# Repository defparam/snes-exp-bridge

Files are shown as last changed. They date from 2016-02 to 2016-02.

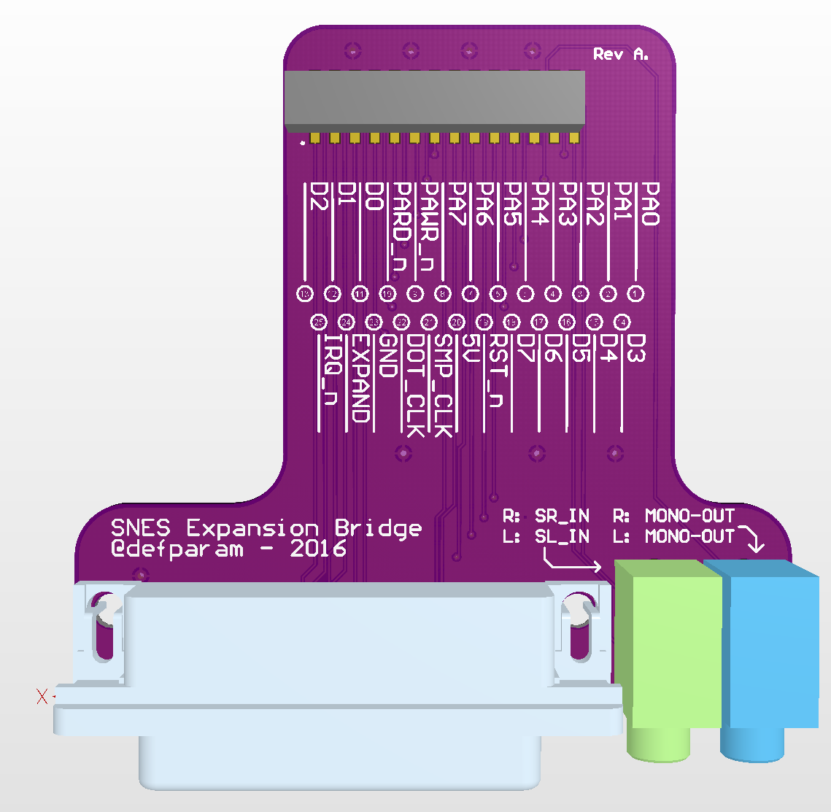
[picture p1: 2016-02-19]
photos/board1.png

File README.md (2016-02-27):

# snes-exp-bridge
This project is intended to create a bridge board interface to the SNES expansion port broken out to DB-25 and 3.5mm barrel audio. The expansion port requires a costly proprietary connector from SAMTEC (MEC2-30-01-L-DV). The idea is instead of creating projects which source this connector, all downstream projects can now instead mate with the DB-25 connector which is cheaper and easier for interfacing. There are no active electrical components for this board. This repo contains altium design files of the schematic/layout, photos and pdf docs.

Enjoy!
Evan

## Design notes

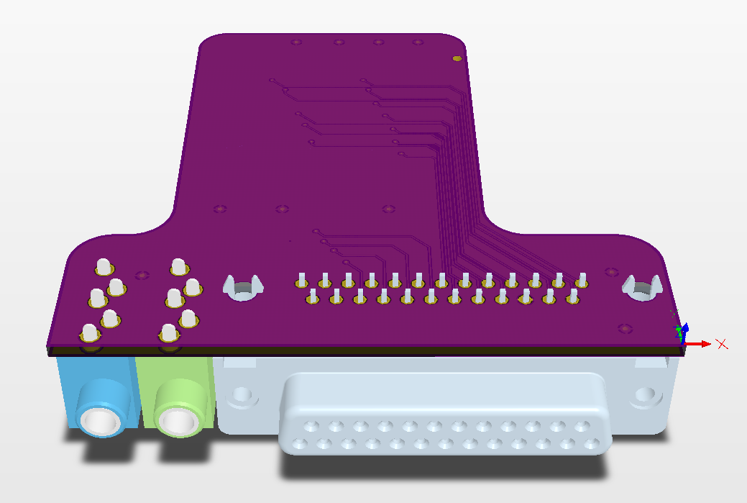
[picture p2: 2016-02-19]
photos/board3.png

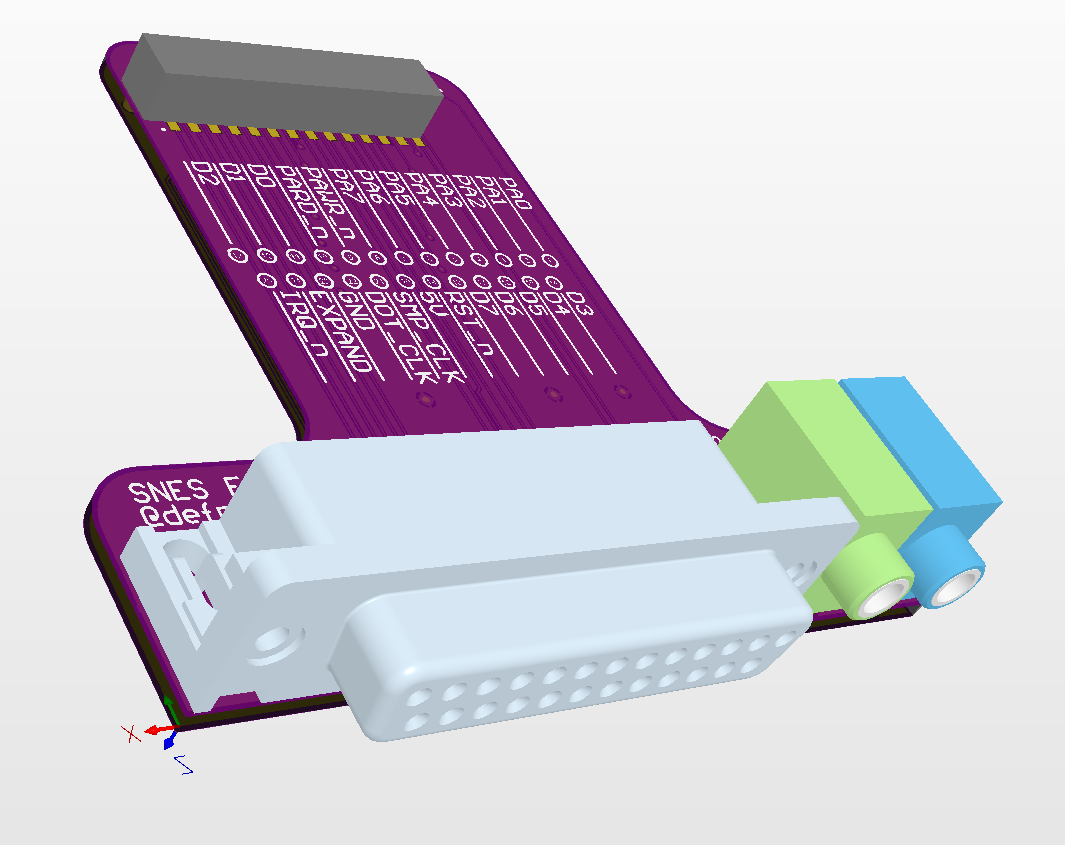
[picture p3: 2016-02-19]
photos/board2.png

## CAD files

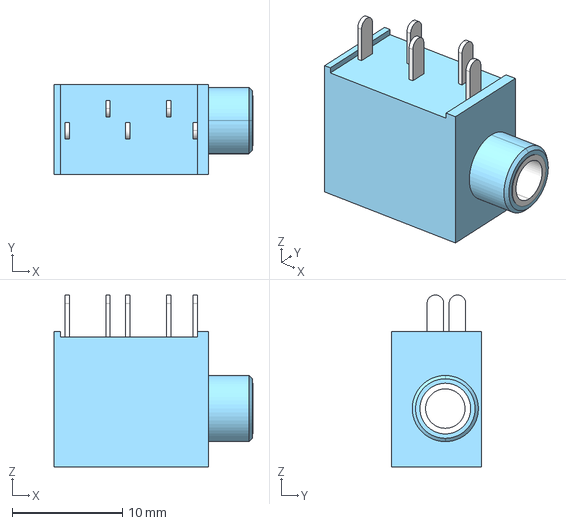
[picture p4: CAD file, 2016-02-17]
altium/step/SJ1-3535NG-BE.stp
18.1 x 8.20 x 15.6 mm

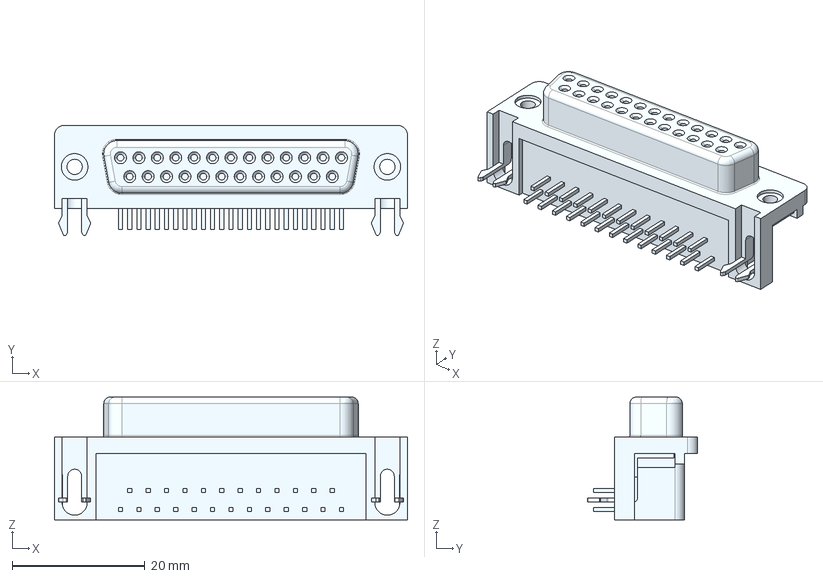
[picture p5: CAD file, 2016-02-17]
altium/step/TE_conn_DB_25.stp
53.1 x 16.6 x 18.5 mm

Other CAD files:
altium/step/SJ1-3535NG-GR.stp

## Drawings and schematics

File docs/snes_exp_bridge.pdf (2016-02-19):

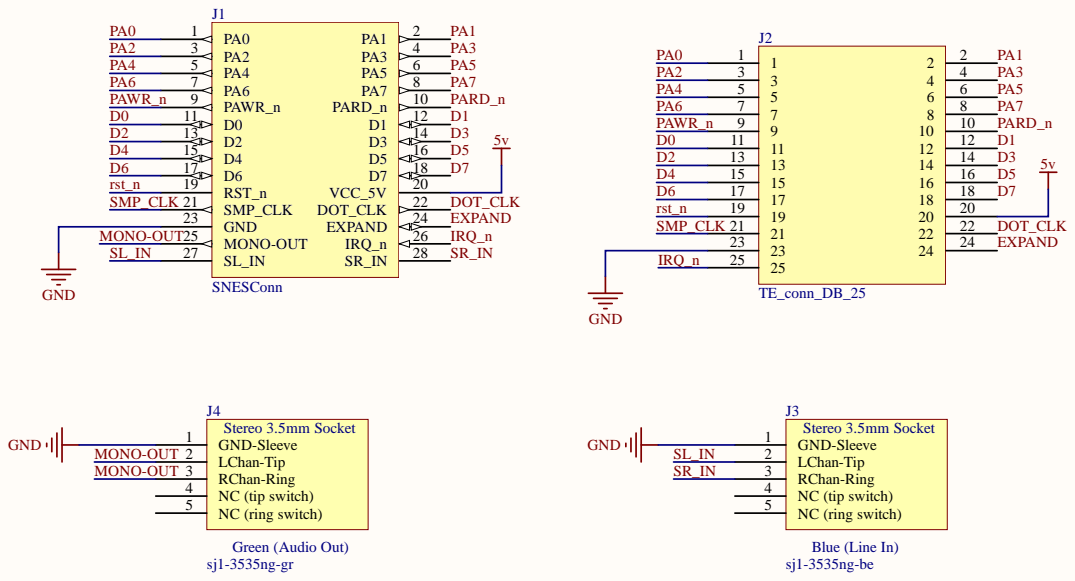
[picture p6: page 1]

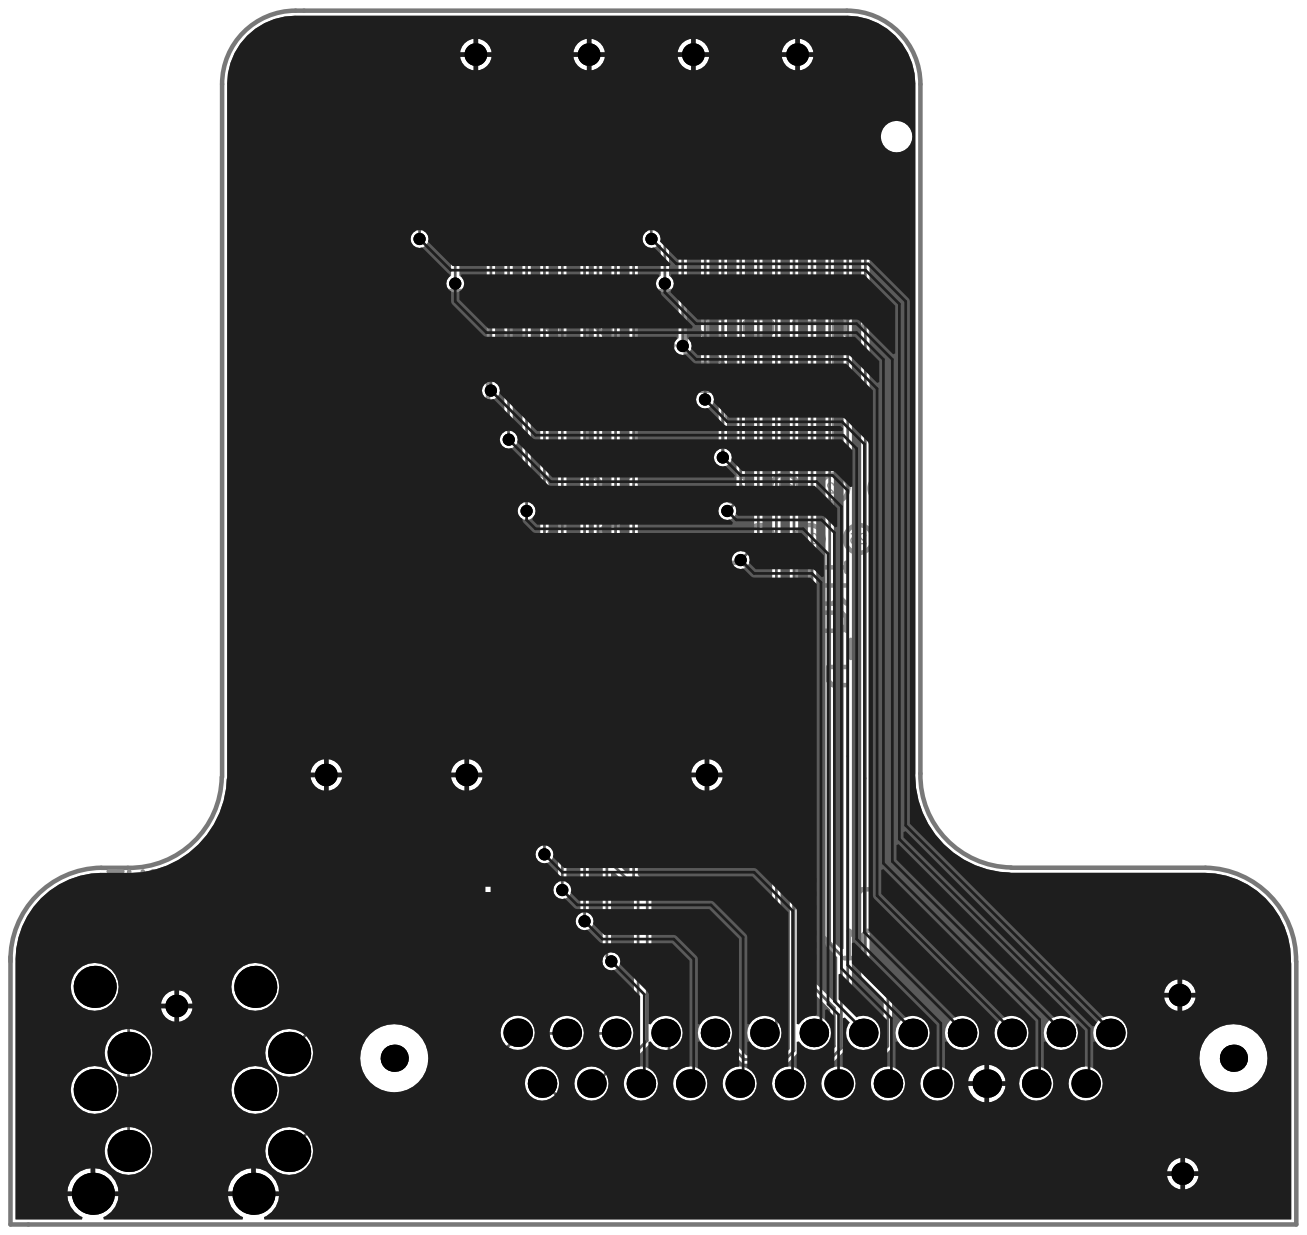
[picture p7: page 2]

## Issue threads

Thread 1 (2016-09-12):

BOM

qwertymodo, 2016-09-12:
Can you post the part numbers for the connectors used?  I know there's basically just 2 parts, so a full BOM is probably overkill, but mostly I'm trying to figure out what audio jack you're using.  The DB-25 connector is probably pretty standard, but audio barrel jacks come in all kinds of shapes, sizes, and footprints.

defparam, 2016-09-12:
For EXP BOARD notable parts (digikey links):

TE Connectivity 1734350-1 - https://www.digikey.com/product-detail/en/te-connectivity-amp-connectors/1734350-1/A35111-ND/1279824
CUI Inc. SJ1-3535NG-GR - https://www.digikey.com/product-detail/en/cui-inc/SJ1-3535NG-GR/CP1-3535NG-GR-ND/2295993
CUI Inc. SJ1-3535NG-BE - https://www.digikey.com/product-detail/en/cui-inc/SJ1-3535NG-BE/CP1-3535NG-BE-ND/2295992

For 21FX Rev C notable parts (digikey links):

3M 8432-11B1-RK-TP - https://www.digikey.com/product-detail/en/3m/8432-11B1-RK-TP/3M3211B1-ND/1026472
Microchip SST39SF010A-70-4C-NHE - https://www.digikey.com/product-detail/en/microchip-technology/SST39SF010A-70-4C-NHE/SST39SF010A-70-4C-NHE-ND/2297825
Norcomp Inc. 182-025-113R531 - https://www.digikey.com/product-detail/en/norcomp-inc/182-025-113R531/182-25ME-ND/858361

The holes I used for the audio connectors are not slotted (because OSHPark doesn't do plated slots). So Those holes are really large however it still works for those parts. If you aren't using audio you can safely omit the audio connectors as they are fairly expensive. Since you are looking at 21FX I also put some parts I used above. FYI you need an external programmer to program byuu's IPLROM onto the microchip EEPROM. Lastly for the 21FX you need the adafruit FTDI board (yeahhh, 21FX needs a tech refresh, it was intended originally to not have USB).

qwertymodo, 2016-09-12:
Perfect, thanks.

defparam, 2016-09-12:
21FX (couple more parts I missed):

CTS CB3-3I-40M0000 - https://www.digikey.com/product-detail/en/cts-frequency-controls/CB3-3I-40M0000/CTX314CT-ND/663676
Altera EPM7064STC44-10N - https://www.digikey.com/product-detail/en/altera/EPM7064STC44-10N/544-2020-ND/1084671
Adafruit 232H breakout - https://www.adafruit.com/products/2264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

Closed 2016-09-12.

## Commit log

2016-02-14 Adding EXP-Bridge project to GitHub
    [snes_exp_bridge.PcbDoc, snes_exp_bridge.PrjPcb, snes_exp_bridge.SchDoc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]
2016-02-17 Adding step files
    [SJ1-3535NG-BE.stp, SJ1-3535NG-GR.stp, TE_conn_DB_25.stp]
2016-02-17 REV A Final
    [snes_exp_bridge.PcbDoc, snes_exp_bridge.PrjPcb, snes_exp_bridge.SchDoc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]
2016-02-19 Updating final design files, modified license, added PDF schematic and photos.
    [snes_exp_bridge.PcbDoc, snes_exp_bridge.PrjPcb, snes_exp_bridge_parts.PcbLib]
2016-04-14 Fixed severe errata with the pinout. Interface should be pin flipped
    [snes_exp_bridge.PcbDoc, snes_exp_bridge.SchDoc]
2016-09-11 Adding gerbers/drills for extra open-sourcy-ness :)
    [snes_exp_bridge.GBL, snes_exp_bridge.GBO, snes_exp_bridge.GBP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]
